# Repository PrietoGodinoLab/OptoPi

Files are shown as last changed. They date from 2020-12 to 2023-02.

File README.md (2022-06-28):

# OptoPi

### OptoPi Overview


Here, we present OptoPi, an open source, affordable (~ £600), behavioural arena with accompanying multi-animal tracking software. The system features highly customisable and reproducible visible and infrared illumination and allows for temporally precise optogenetic stimulation. OptoPi acquires images using a Raspberry Pi camera, features motorised LED-based illumination, Arduino control, as well as spectrum and irradiance monitoring to fine-tune
illumination conditions with real time feedback.

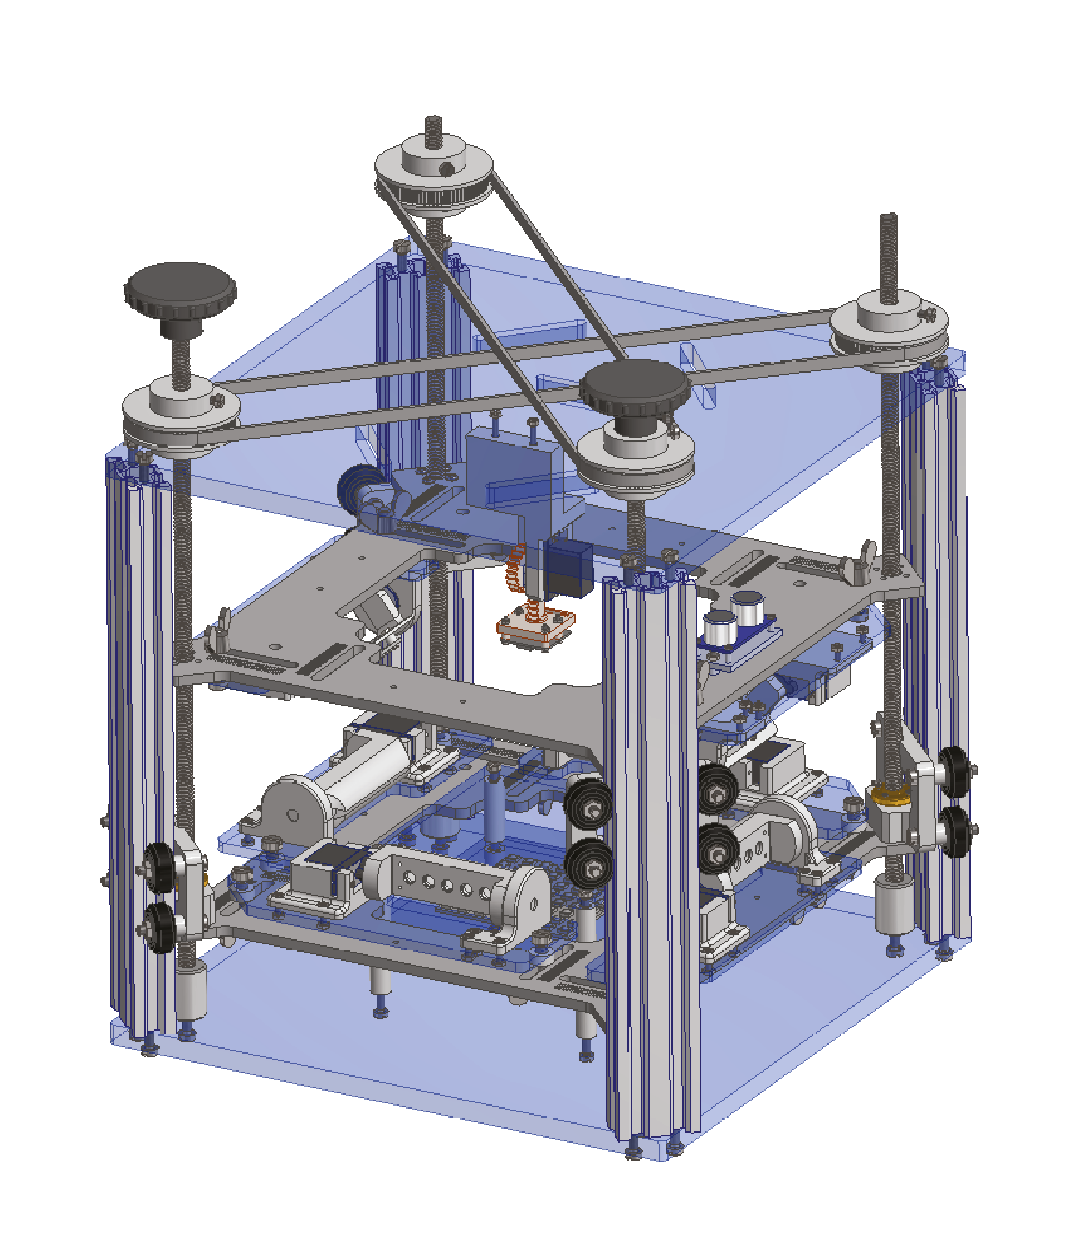
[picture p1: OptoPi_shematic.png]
 
Our open-source software (BIO) can be used to simultaneously track multiple animals while accurately keeping individual animal’s identity both in on-line and off-line modes. 

## BIO

For animal tracking we utilise and recommend BIO created by Joost de Folter. Currently, we use the [v1.7.6 release](https://github.com/folterj/BioImageOperation/releases/tag/v1.7.6). For the latest, actively maintained BIO repository see [BIO](https://github.com/folterj/BioImageOperation).

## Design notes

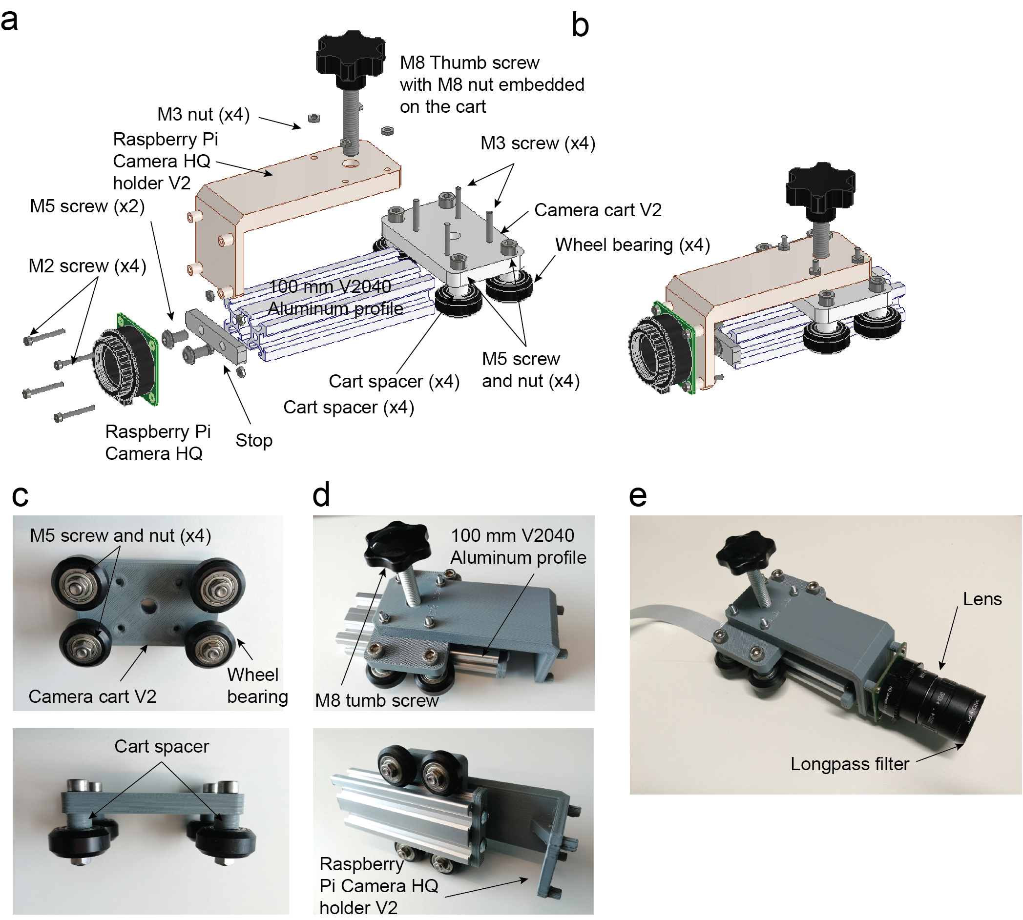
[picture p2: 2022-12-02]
OptoPi V1/Optional mechanical camera stage/Figure 10(2).png

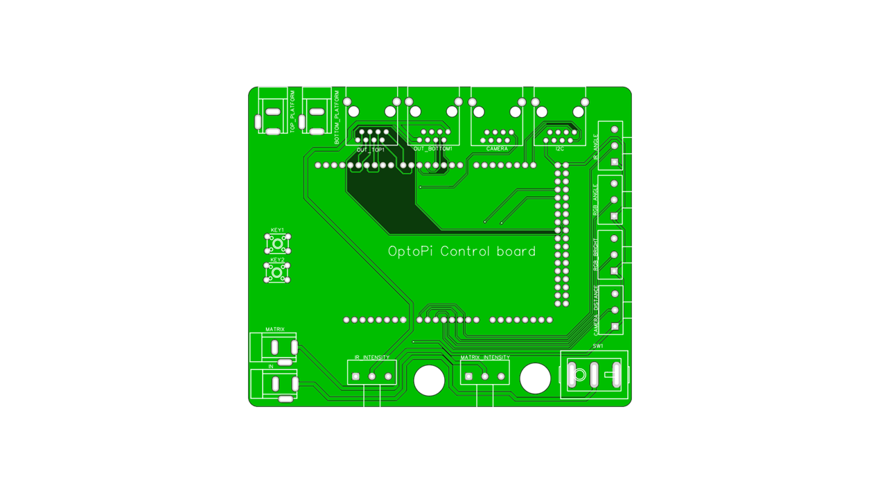
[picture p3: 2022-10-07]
OptoPi V1/Electronics Boards/Control board PCB/Control board.PNG

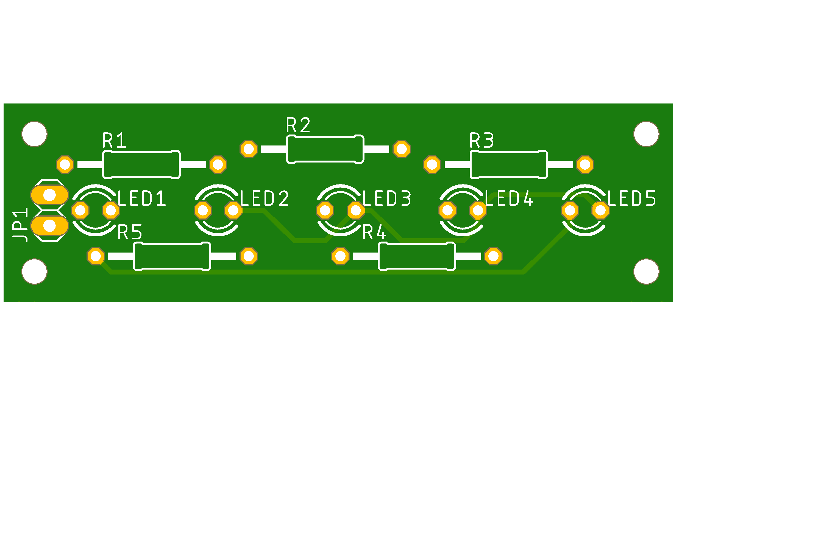
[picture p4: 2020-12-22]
OptoPi V1/Electronics Boards/IR LED Array PCB/LED ArrayTop.png

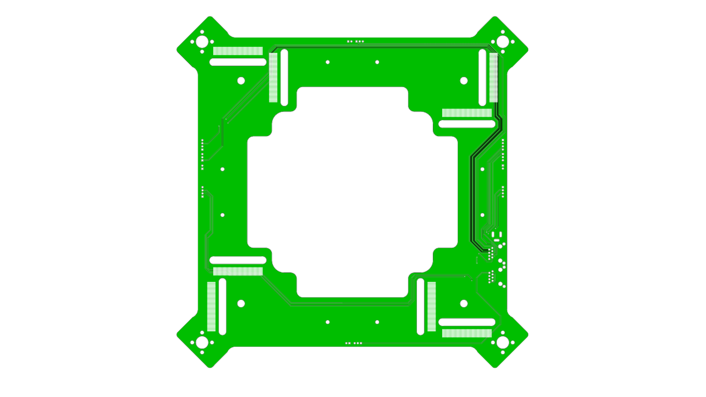
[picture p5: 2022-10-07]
OptoPi V1/Electronics Boards/Platform PCB/Platform.PNG

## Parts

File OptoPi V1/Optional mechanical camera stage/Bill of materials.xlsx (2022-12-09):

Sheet: Sheet1
BOM
1PC Silver V-slot 2040 European Standard Anodized Aluminum Profile Extrusion 100 | https://www.amazon.co.uk/KIRANDY-European-Standard-Extrusion-100-800mm/dp/B0B5Z3GMF8
2.1 mm Jack cables | https://www.amazon.co.uk/RUNCCI-YUN-Pigtail-Connector-connector-Systems/dp/B08ZMM8V3B
RJ45 connectors | https://uk.farnell.com/multicomp/mtj-881x1/modular-jack-tht-r-a-rj45-8p8c/dp/2112501
Barrel jack connectors (PCB) | https://uk.farnell.com/cliff-electronic-components/fc68148/socket-pcb-dc-power-2-1mm-pk10/dp/224959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
Control PCB
Platform PCB
M8 Thumb screw | https://www.amazon.co.uk/dp/B098JPSYMB?amp=&amp=
Ethernet cable (x2)
Power cable (Barrel jack male) (x2)

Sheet: Sheet2
Component | Quantity | Source
1PC Silver V-slot 2040 European Standard Anodized Aluminum Profile Extrusion 100 | 1 | Amazon (https://www.amazon.co.uk/KIRANDY-European-Standard-Extrusion-100-800mm/dp/B0B5Z3GMF8)
M8 Thumb screw | 1 | Amazon (https://www.amazon.co.uk/dp/B098JPSYMB?amp=&amp=)
Wheel bearing | 4 | Amazon (https://www.amazon.co.uk/gp/product/B07Q5WN3GK/ref=ppx_yo_dt_b_asin_title_o05_s00?ie=UTF8&psc=1)
M8 nut | 1
M3 screws (35 mm length) | 4
M3 nuts | 4
M5 screws (35 mm length) | 4
M5 nuts | 4
M5 screws (10 mm length) | 2
3D printed parts
Raspberry Pi HQ holder V2 | 1 | GitHub/OSFRepository
Camera cart V2 | 1 | GitHub/OSFRepository
Spacers | 4 | GitHub/OSFRepository
Stop | 5 | GitHub/OSFRepository

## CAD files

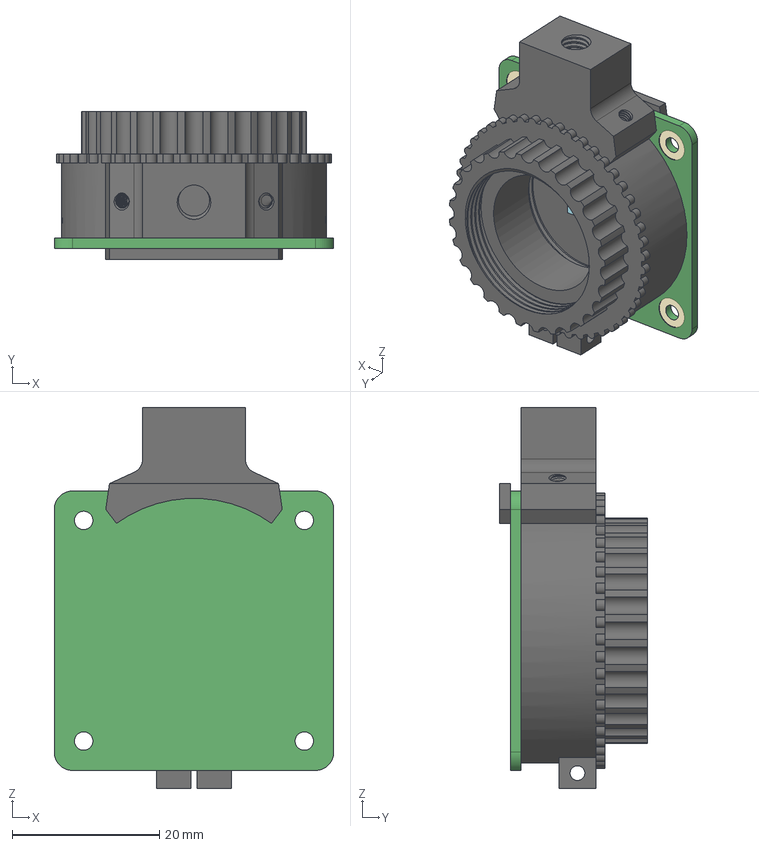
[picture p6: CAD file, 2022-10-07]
OptoPi V1/Mechanical components/Design files/Inventor Assembly/Raspberry Pi HQ Camera.step
38.0 x 20.1 x 51.8 mm

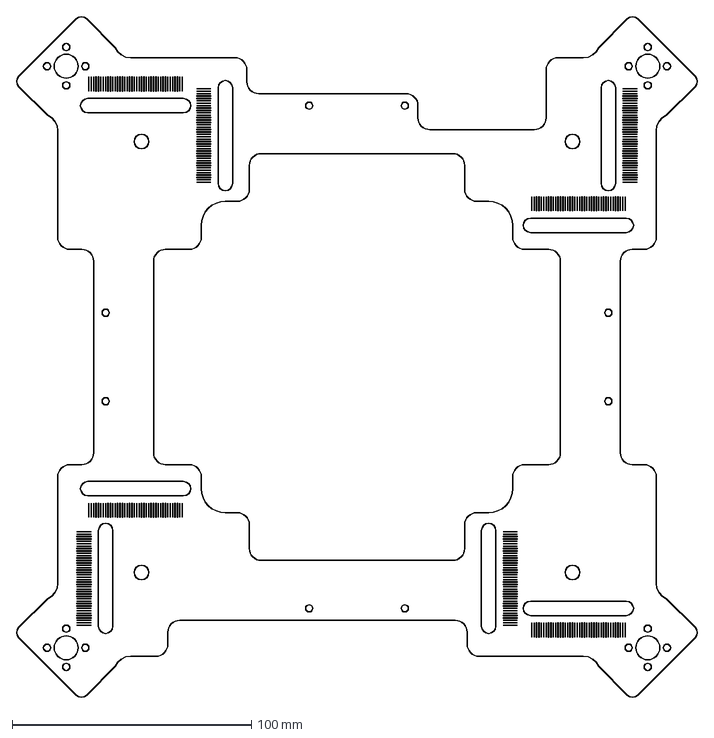
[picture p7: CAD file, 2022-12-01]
OptoPi V1/Mechanical components/DXF files/Platform/Platform spacer.dxf
284.9 x 284.9 mm

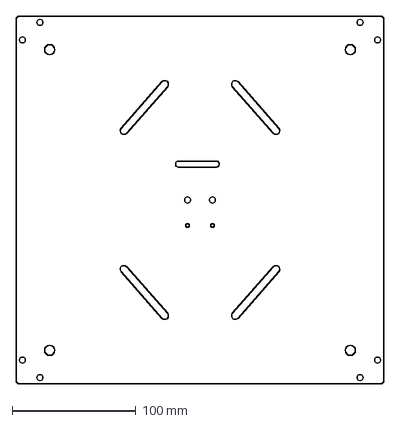
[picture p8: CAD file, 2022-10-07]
OptoPi V1/Mechanical components/DXF files/Structure/Roof.dxf
297.0 x 297.0 mm

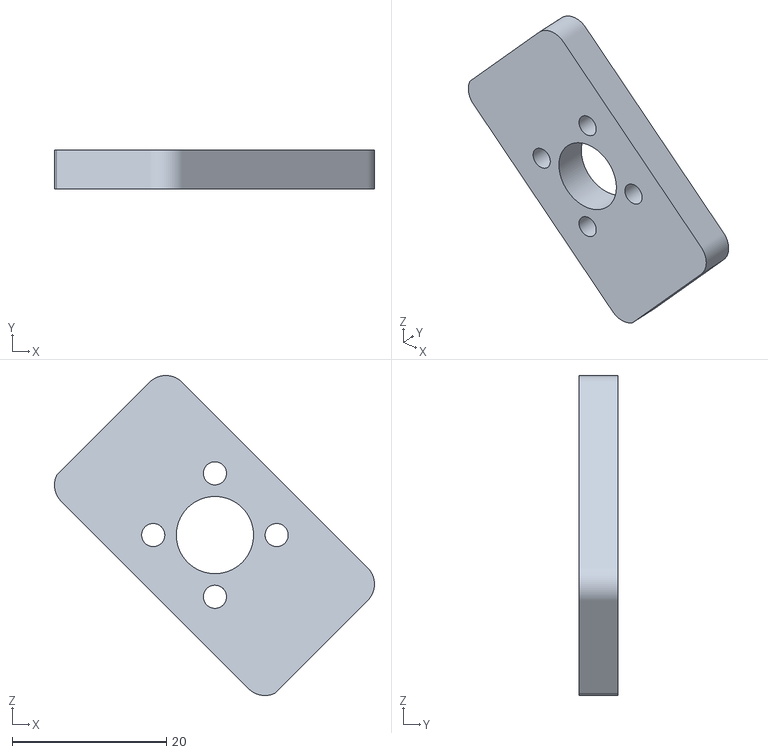
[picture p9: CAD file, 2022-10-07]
OptoPi V1/Mechanical components/STL files/Platform/Light sources platform spacer.stl
41.5 x 5.00 x 41.5

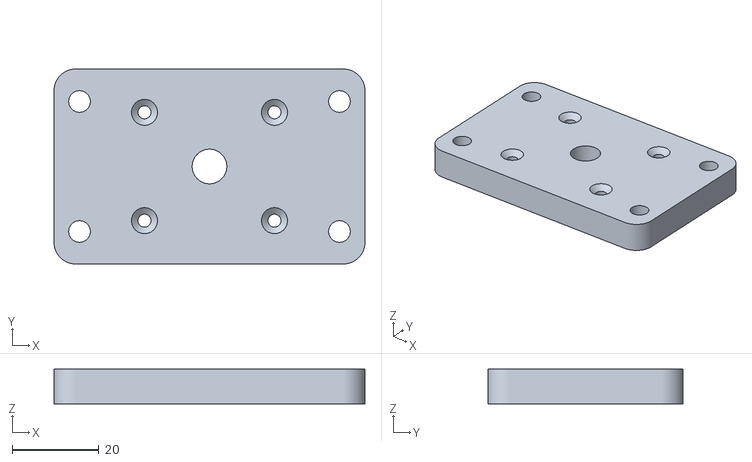
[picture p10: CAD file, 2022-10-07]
OptoPi V1/Optional mechanical camera stage/STL files/Camera_cart_V2.stl
71.8 x 45.0 x 8.00

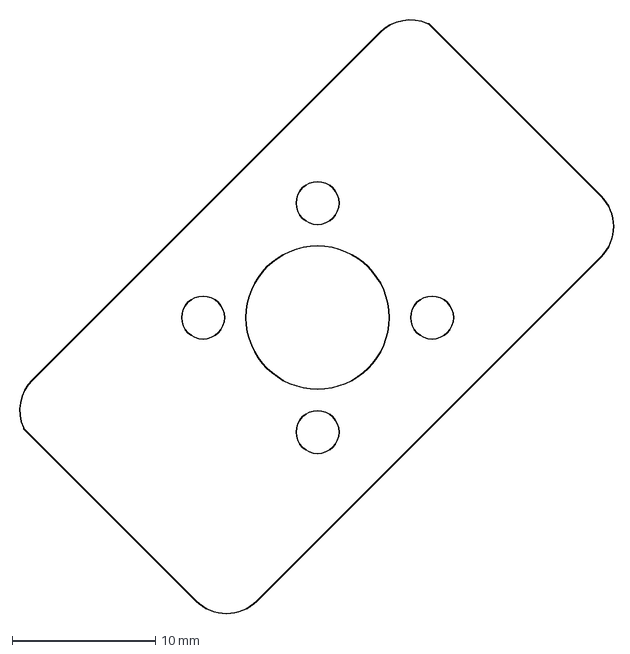
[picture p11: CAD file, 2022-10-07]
OptoPi V1/Mechanical components/Design files/Inventor Assembly/New parts/Light sources platform spacer.dxf
41.7 x 41.7 mm

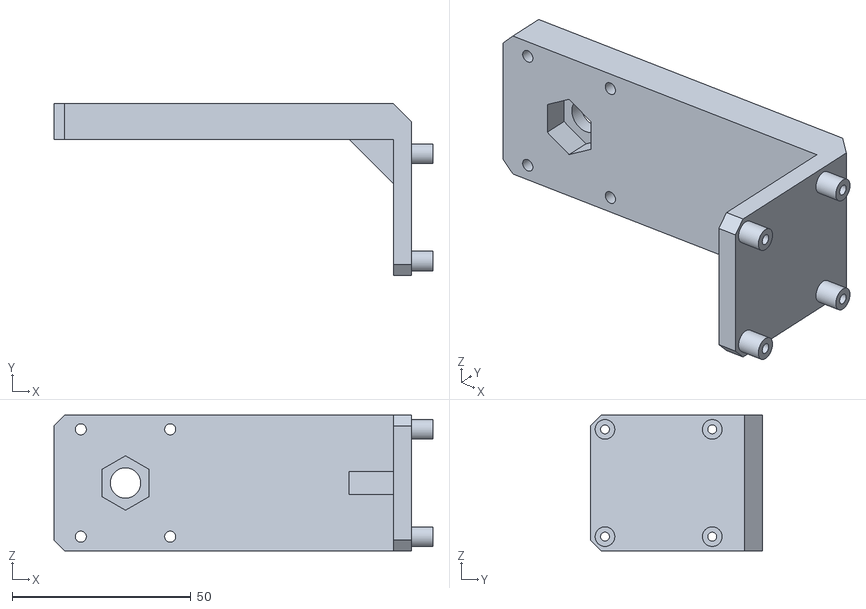
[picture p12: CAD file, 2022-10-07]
OptoPi V1/Optional mechanical camera stage/STL files/Raspberry pi HQ camera holder V2.stl
106.0 x 48.0 x 38.0

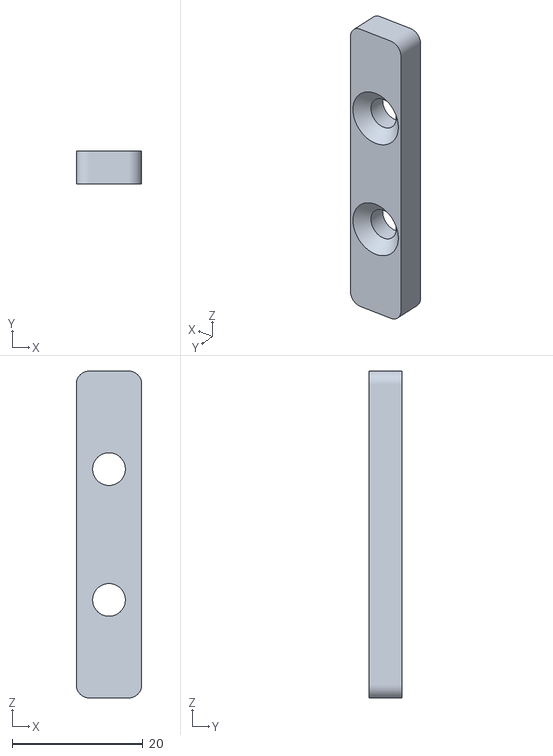
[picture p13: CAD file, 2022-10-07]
OptoPi V1/Optional mechanical camera stage/STL files/Stop.stl
10.0 x 5.00 x 50.0

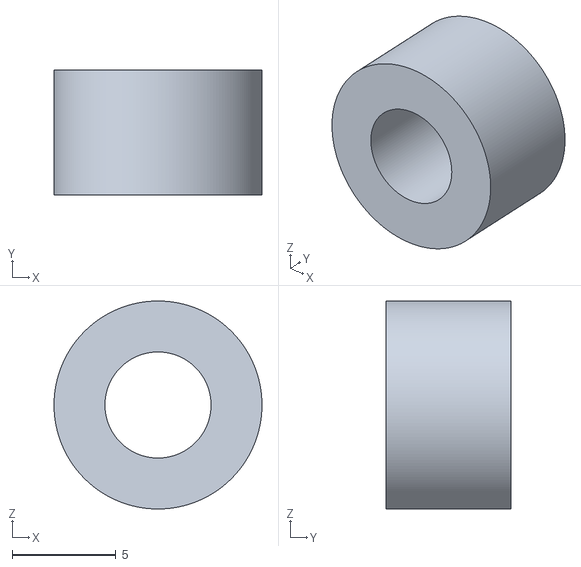
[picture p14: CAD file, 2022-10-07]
OptoPi V1/Optional mechanical camera stage/STL files/cart_spacer.stl
10.0 x 6.00 x 10.0

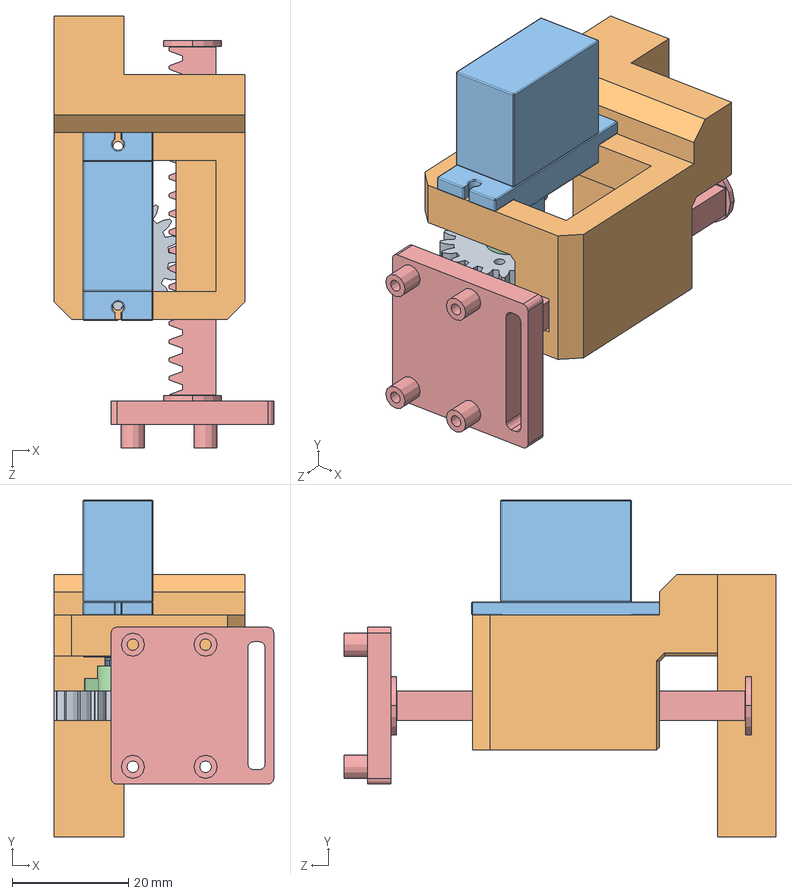
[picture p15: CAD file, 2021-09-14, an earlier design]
OptoPi V0/Mechanical components/Design files (Step and Autodesk inventor)/Inventor Assembly/Servo based linear actuator Pi Camera/Linear actuator assem 1.SLDASM
37.8 x 57.9 x 74.2 mm
ISO - Spur gear 1M 20T 20PA 5FW ---S20A75H50L5.0N
Linear actuator servo attachment
MG90s_servo
Servo lever
ISO - Rack-spur - rectangular 1M 20PA 5FW 5PH 125L---SAll

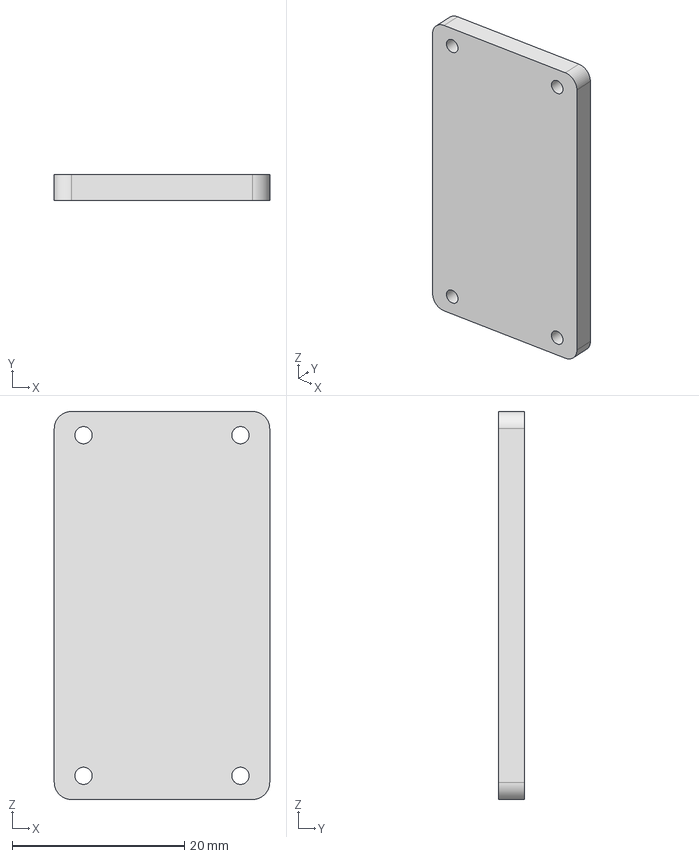
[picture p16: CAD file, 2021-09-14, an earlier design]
OptoPi V0/Electronics Boards/1-6 Connector/1-6 connector base.stp
25.0 x 3.00 x 45.0 mm

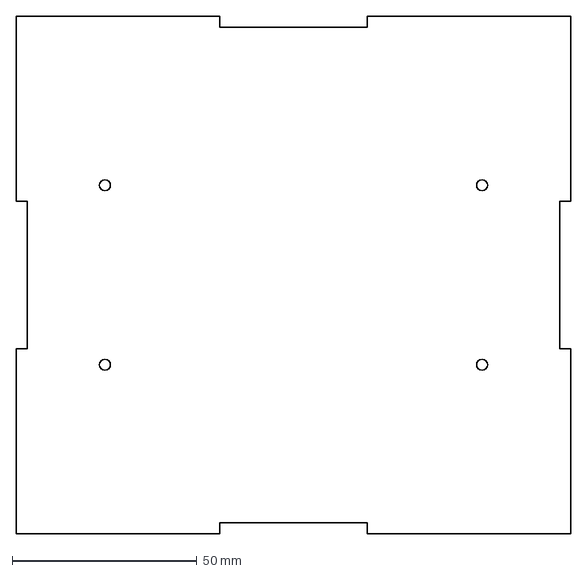
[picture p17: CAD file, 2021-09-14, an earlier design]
OptoPi V0/Electronics Boards/Electronics box/Electronics base.dxf
150.0 x 140.0 mm

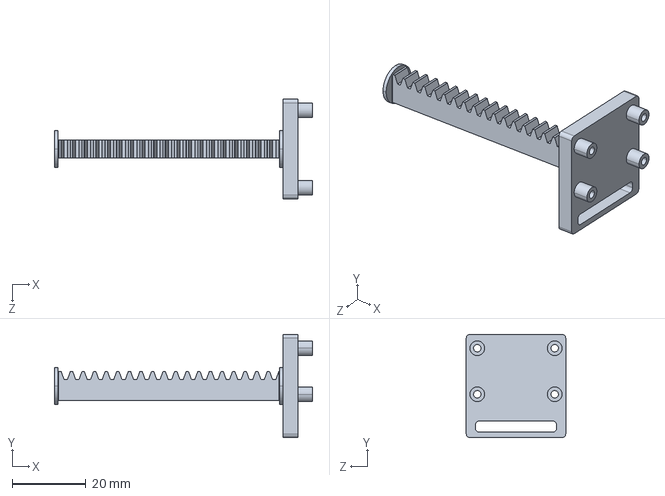
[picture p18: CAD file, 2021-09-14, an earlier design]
OptoPi V0/Mechanical components/Design files (Step and Autodesk inventor)/Inventor Assembly/Servo based linear actuator Pi Camera/ISO - Rack-spur - rectangular 1M 20PA 5FW 5PH 125L---SAll.STEP
70.0 x 28.0 x 27.0 mm

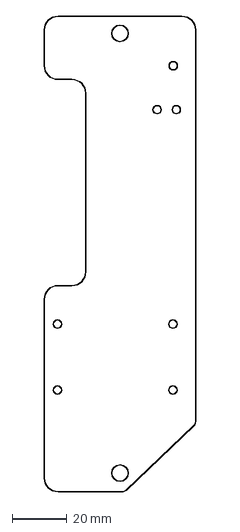
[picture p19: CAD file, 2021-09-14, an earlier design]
OptoPi V0/Mechanical components/Design files (Step and Autodesk inventor)/Inventor Assembly/Servo system holder.dxf
55.0 x 173.0 mm

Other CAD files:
OptoPi V1/Mechanical components/Design files/Inventor Assembly/Camera stage V2/Roof V2.dwg
OptoPi V1/Mechanical components/Design files/Inventor Assembly/New parts/Light sources platform spacer 2.dwg
OptoPi V1/Mechanical components/Design files/Inventor Assembly/New parts/Roof V2.dwg
OptoPi V0/Electronics Boards/1-6 Connector/1-6 connector base.dwg
OptoPi V0/Electronics Boards/1-6 Connector/1-6 connector base.dxf
OptoPi V0/Electronics Boards/1-6 Connector/OldVersions/Plastic base.0001.ipt
OptoPi V0/Electronics Boards/Electronics box/Electronics spacer.dxf
OptoPi V0/Electronics Boards/Electronics box/Lateral 1Wpot.dxf
OptoPi V0/Electronics Boards/Electronics box/Lateral 5Wpot.dxf
OptoPi V0/Electronics Boards/Electronics box/Lateral USB.dxf
OptoPi V0/Electronics Boards/Electronics box/Lateral power.dxf
OptoPi V0/Mechanical components/DXF files/Arena/Arena.dxf
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

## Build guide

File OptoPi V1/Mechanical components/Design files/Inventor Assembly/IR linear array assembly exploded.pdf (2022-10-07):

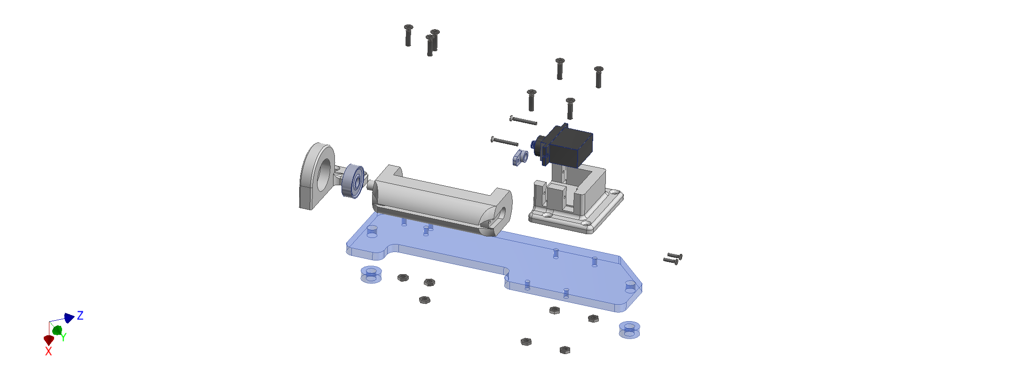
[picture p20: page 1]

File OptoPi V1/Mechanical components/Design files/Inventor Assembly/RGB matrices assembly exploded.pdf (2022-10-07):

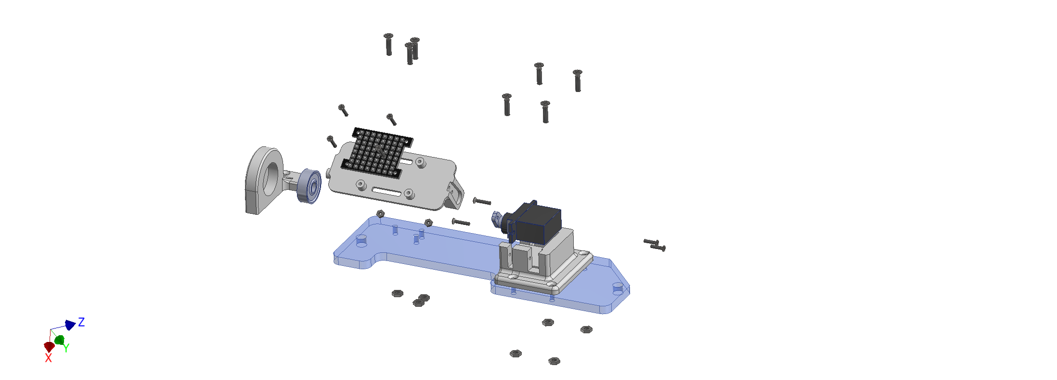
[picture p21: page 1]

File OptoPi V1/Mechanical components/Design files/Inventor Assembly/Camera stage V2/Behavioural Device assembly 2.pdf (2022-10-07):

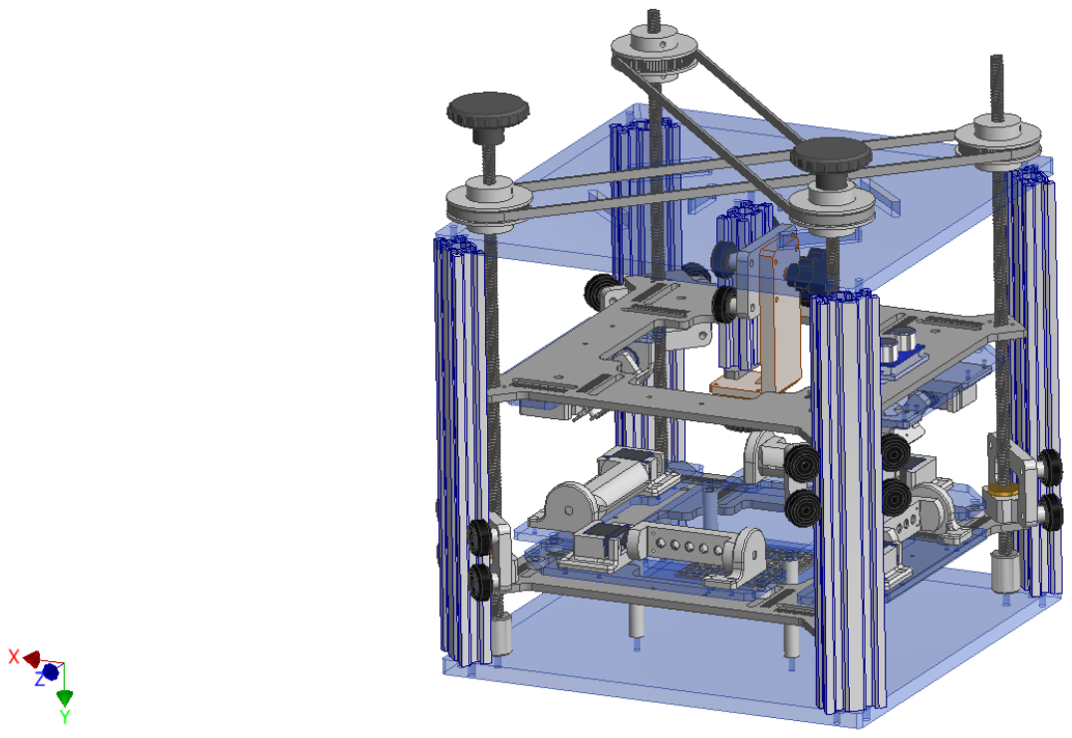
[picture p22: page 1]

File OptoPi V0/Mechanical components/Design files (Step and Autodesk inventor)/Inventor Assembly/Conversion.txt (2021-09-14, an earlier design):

Conversion Report:

Created by DWG TrueView DWG Convert Monday, November 16, 2020, 5:16 PM.

Conversion Summary

------------------

Conversion File Format:  AutoCAD 2004/LT 2004 Drawing Format

Conversion package type: In-place (overwrite files)

Converted DWG files:     2

Recovered DWG files:     0

Conversion errors:       0

Converted Files

---------------

Root Drawings:

	C:\Users\ferrerx\Desktop\CALM Lab\Syringe pump\Rail Syringe pump\Electronics base.dwg

	C:\Users\ferrerx\Desktop\CALM Lab\Syringe pump\Rail Syringe pump\Motor holder.dwg

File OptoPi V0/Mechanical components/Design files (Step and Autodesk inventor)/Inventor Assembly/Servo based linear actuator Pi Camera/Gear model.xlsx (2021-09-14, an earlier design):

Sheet: Sheet1
Cremallera |  | Gear
Modulo ( M ) | 1.00 | Numero de dientes ( N ) | 20
Paso ( P ) | 3.14 | Modulo ( M ) | 1.00
Altura total del diente ( H ) | 2.17 | Diametro primitivo (Dp) | 20.00
Espesor del diente ( e ) | 1.57 | Diametro exterior ( De ) | 22.00
( c ) | 1.57 | Altura del diente ( H ) | 2.17
Altura de la cabeza del diente ( L ) | 1.00
Semi angulo del diente ( α ) | 0.35
Radio del pie del diente ( r ) | 0.30 | Length (max)
Ancho del fondo del diente ( T ) | 0.84 | 125.6637061

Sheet: Sheet2
g | 9.81
S1 | 0.0115
S2 | 0.002
H | 0.045
t | 0.550750114

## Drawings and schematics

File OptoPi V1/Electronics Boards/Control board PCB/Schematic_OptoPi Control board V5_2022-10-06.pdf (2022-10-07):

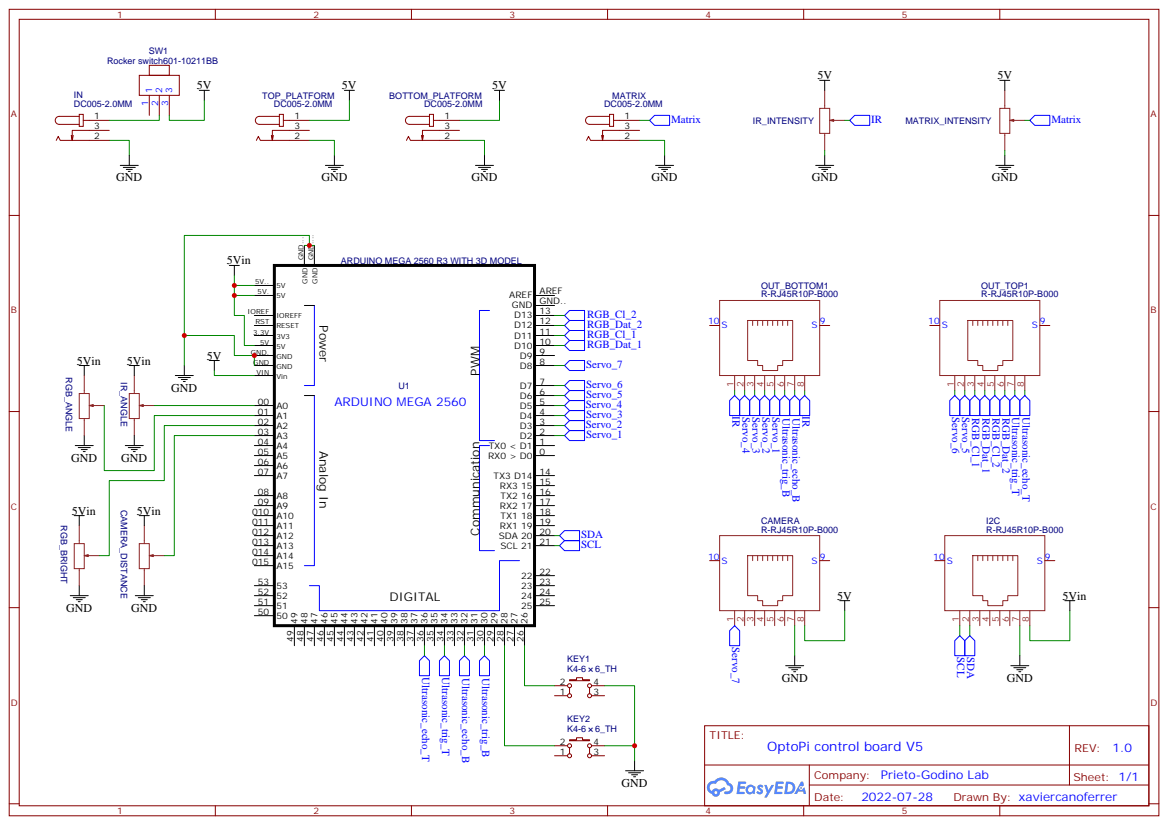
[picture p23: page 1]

GND GND....
ARDUINO MEGA 2560 R3 WITH 3D MODEL

Company: Prieto-Godino Lab

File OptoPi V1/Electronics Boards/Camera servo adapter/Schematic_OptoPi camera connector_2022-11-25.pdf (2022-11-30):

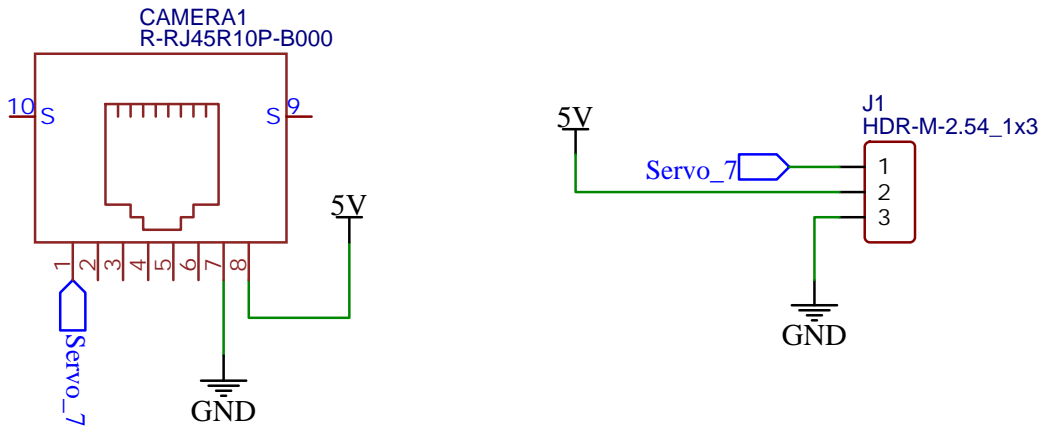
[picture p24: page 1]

Company: Prieto-Godino Lab

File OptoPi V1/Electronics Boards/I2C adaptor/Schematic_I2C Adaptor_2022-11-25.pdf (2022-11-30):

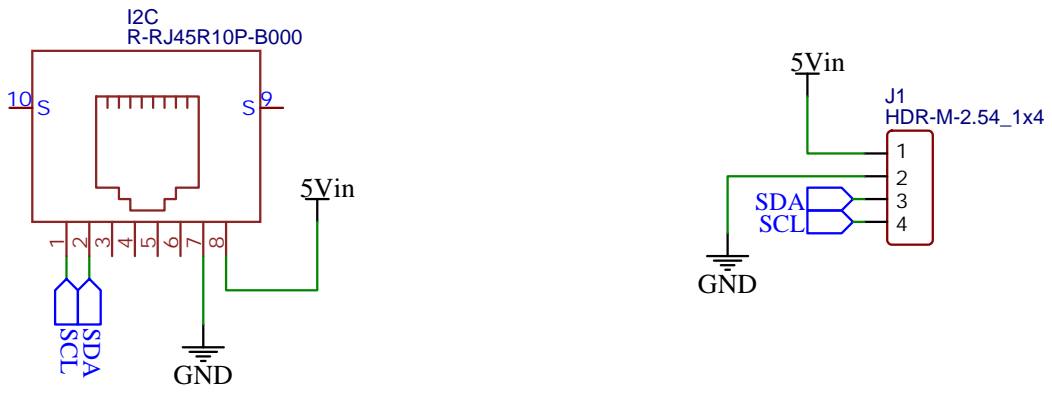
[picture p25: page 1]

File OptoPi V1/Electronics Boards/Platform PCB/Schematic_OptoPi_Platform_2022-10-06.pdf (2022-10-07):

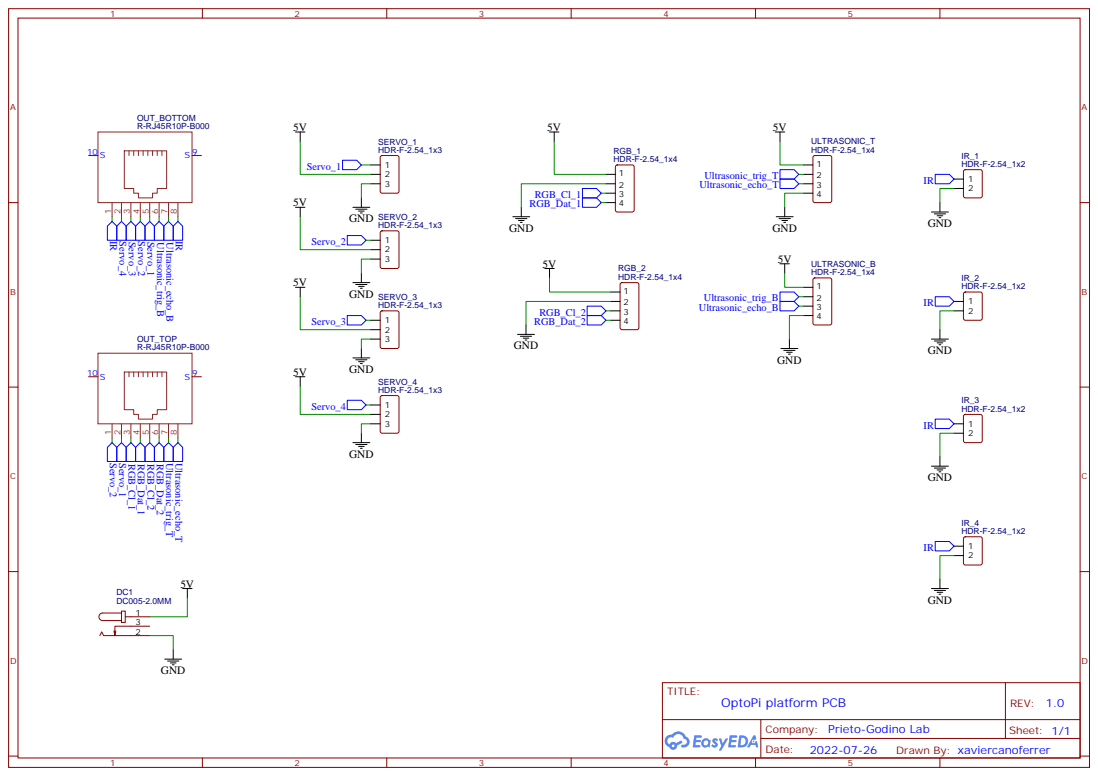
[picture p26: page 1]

Company: Prieto-Godino Lab

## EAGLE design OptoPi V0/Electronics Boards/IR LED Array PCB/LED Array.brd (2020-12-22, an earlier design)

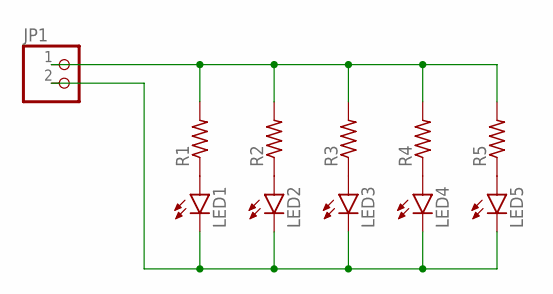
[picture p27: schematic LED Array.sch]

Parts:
JP1: PINHD-1X2; 1X02
LED1, LED2, LED3, LED4, LED5: LED3MM
R1, R2, R3, R4, R5: R-US_0207/12; 0207/12

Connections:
unnamed: LED1.A, R1.1
unnamed: LED3.A, R3.1
unnamed: LED2.A, R2.1
unnamed: LED4.A, R4.1
unnamed: JP1.2, LED1.K (C), LED2.K (C), LED3.K (C), LED4.K (C), LED5.K (C)
unnamed: JP1.1, R1.2, R2.2, R3.2, R4.2, R5.2
unnamed: LED5.A, R5.1

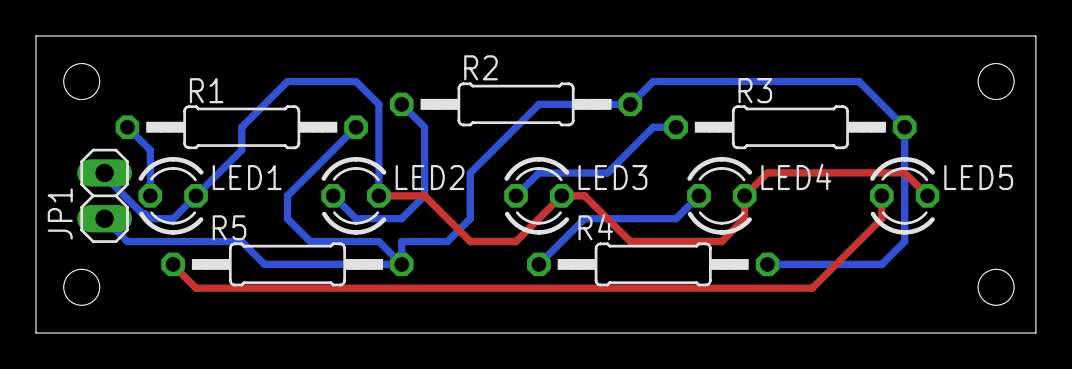
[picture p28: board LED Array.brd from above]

Board: 2 copper layers, 55.5 x 16.5 mm, 11 parts (0 on the bottom side), 7 nets.

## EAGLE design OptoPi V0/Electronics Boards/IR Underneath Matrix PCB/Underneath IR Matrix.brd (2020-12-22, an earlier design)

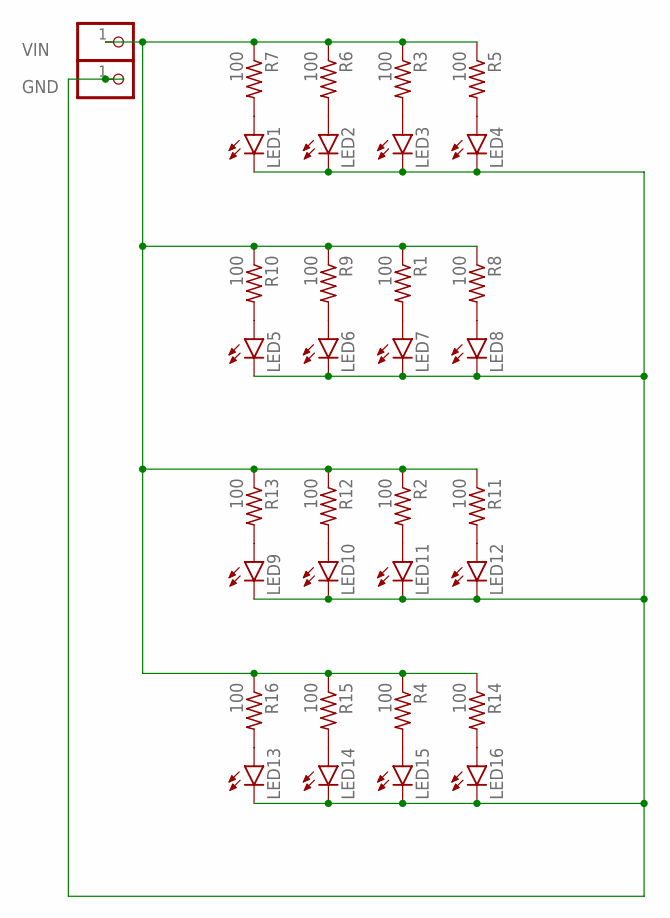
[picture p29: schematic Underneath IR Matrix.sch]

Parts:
GND: PINHD-1X1; 1X01
LED1, LED2, LED3, LED4, LED5, LED6, LED7, LED8, LED9, LED10, LED11, LED12, LED13, LED14, LED15, LED16: LED5MM
R1, R2, R3, R4, R5, R6, R7, R8, R9, R10, R11, R12, R13, R14, R15, R16: 100; 0207/10
VIN: PINHD-1X1; 1X01

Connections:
unnamed: LED5.A, R10.2
unnamed: LED6.A, R9.2
unnamed: LED4.A, R5.2
unnamed: LED8.A, R8.2
unnamed: LED7.A, R1.2
unnamed: LED1.A, R7.2
unnamed: LED2.A, R6.2
unnamed: LED12.A, R11.2
unnamed: GND.1, LED1.K (C), LED2.K (C), LED3.K (C), LED4.K (C), LED5.K (C), LED6.K (C), LED7.K (C), LED8.K (C), LED9.K (C), LED10.K (C), LED11.K (C), LED12.K (C), LED13.K (C), LED14.K (C), LED15.K (C), LED16.K (C)
unnamed: R1.1, R2.1, R3.1, R4.1, R5.1, R6.1, R7.1, R8.1, R9.1, R10.1, R11.1, R12.1, R13.1, R14.1, R15.1, R16.1, VIN.1
unnamed: LED15.A, R4.2
unnamed: LED3.A, R3.2
unnamed: LED9.A, R13.2
unnamed: LED10.A, R12.2
unnamed: LED11.A, R2.2
unnamed: LED13.A, R16.2
unnamed: LED14.A, R15.2
unnamed: LED16.A, R14.2

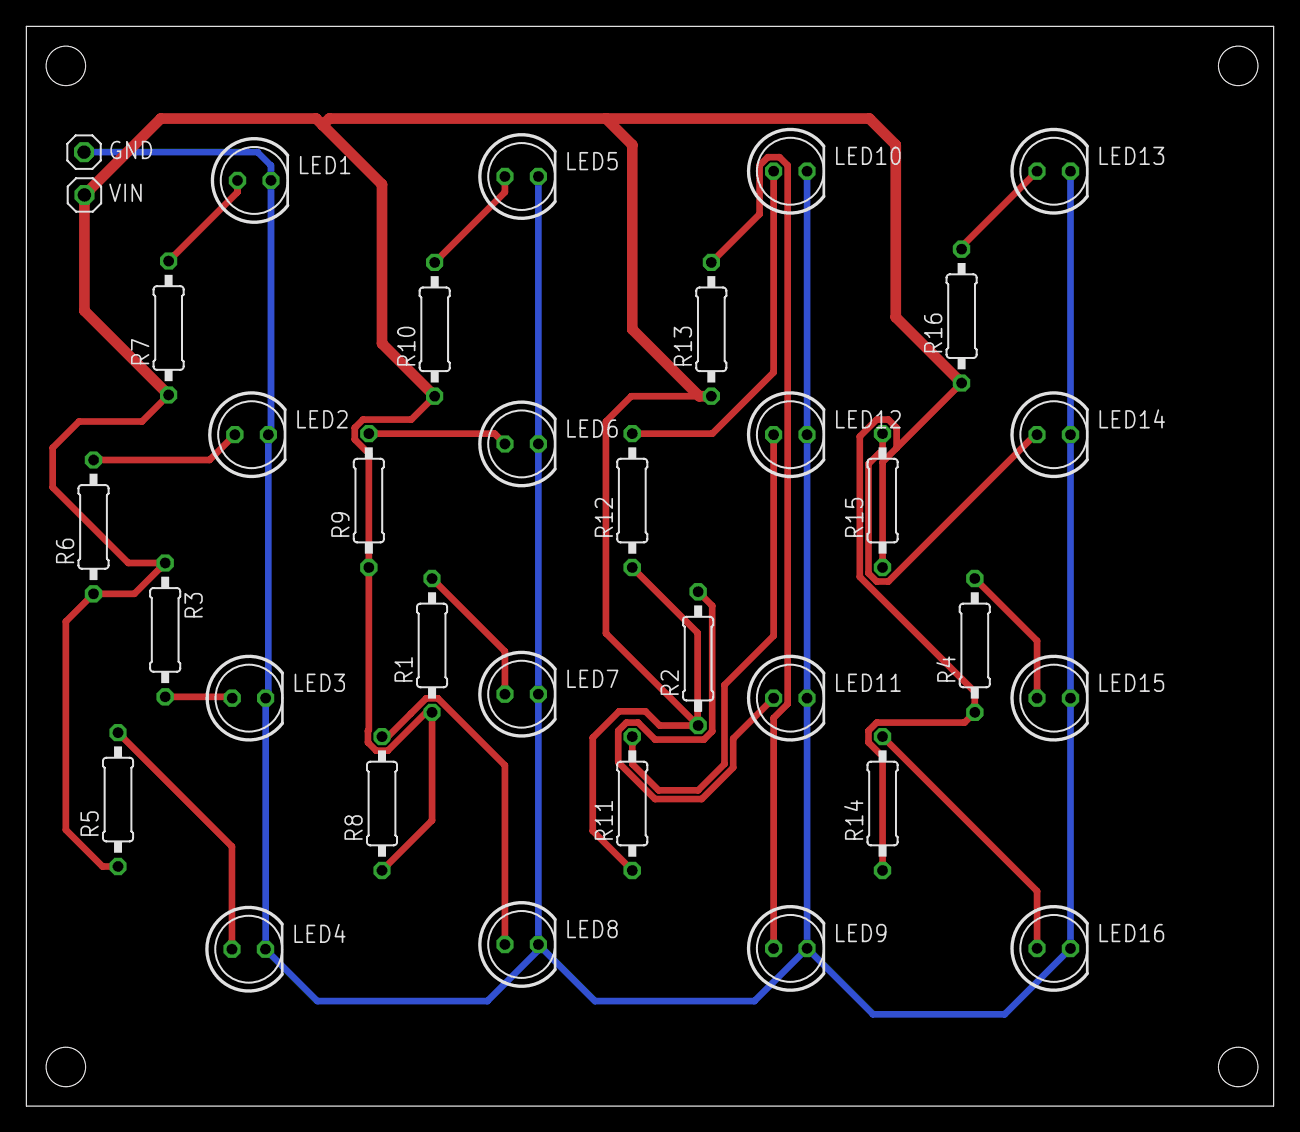
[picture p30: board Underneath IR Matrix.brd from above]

Board: 2 copper layers, 94.7 x 82.0 mm, 34 parts (0 on the bottom side), 18 nets.

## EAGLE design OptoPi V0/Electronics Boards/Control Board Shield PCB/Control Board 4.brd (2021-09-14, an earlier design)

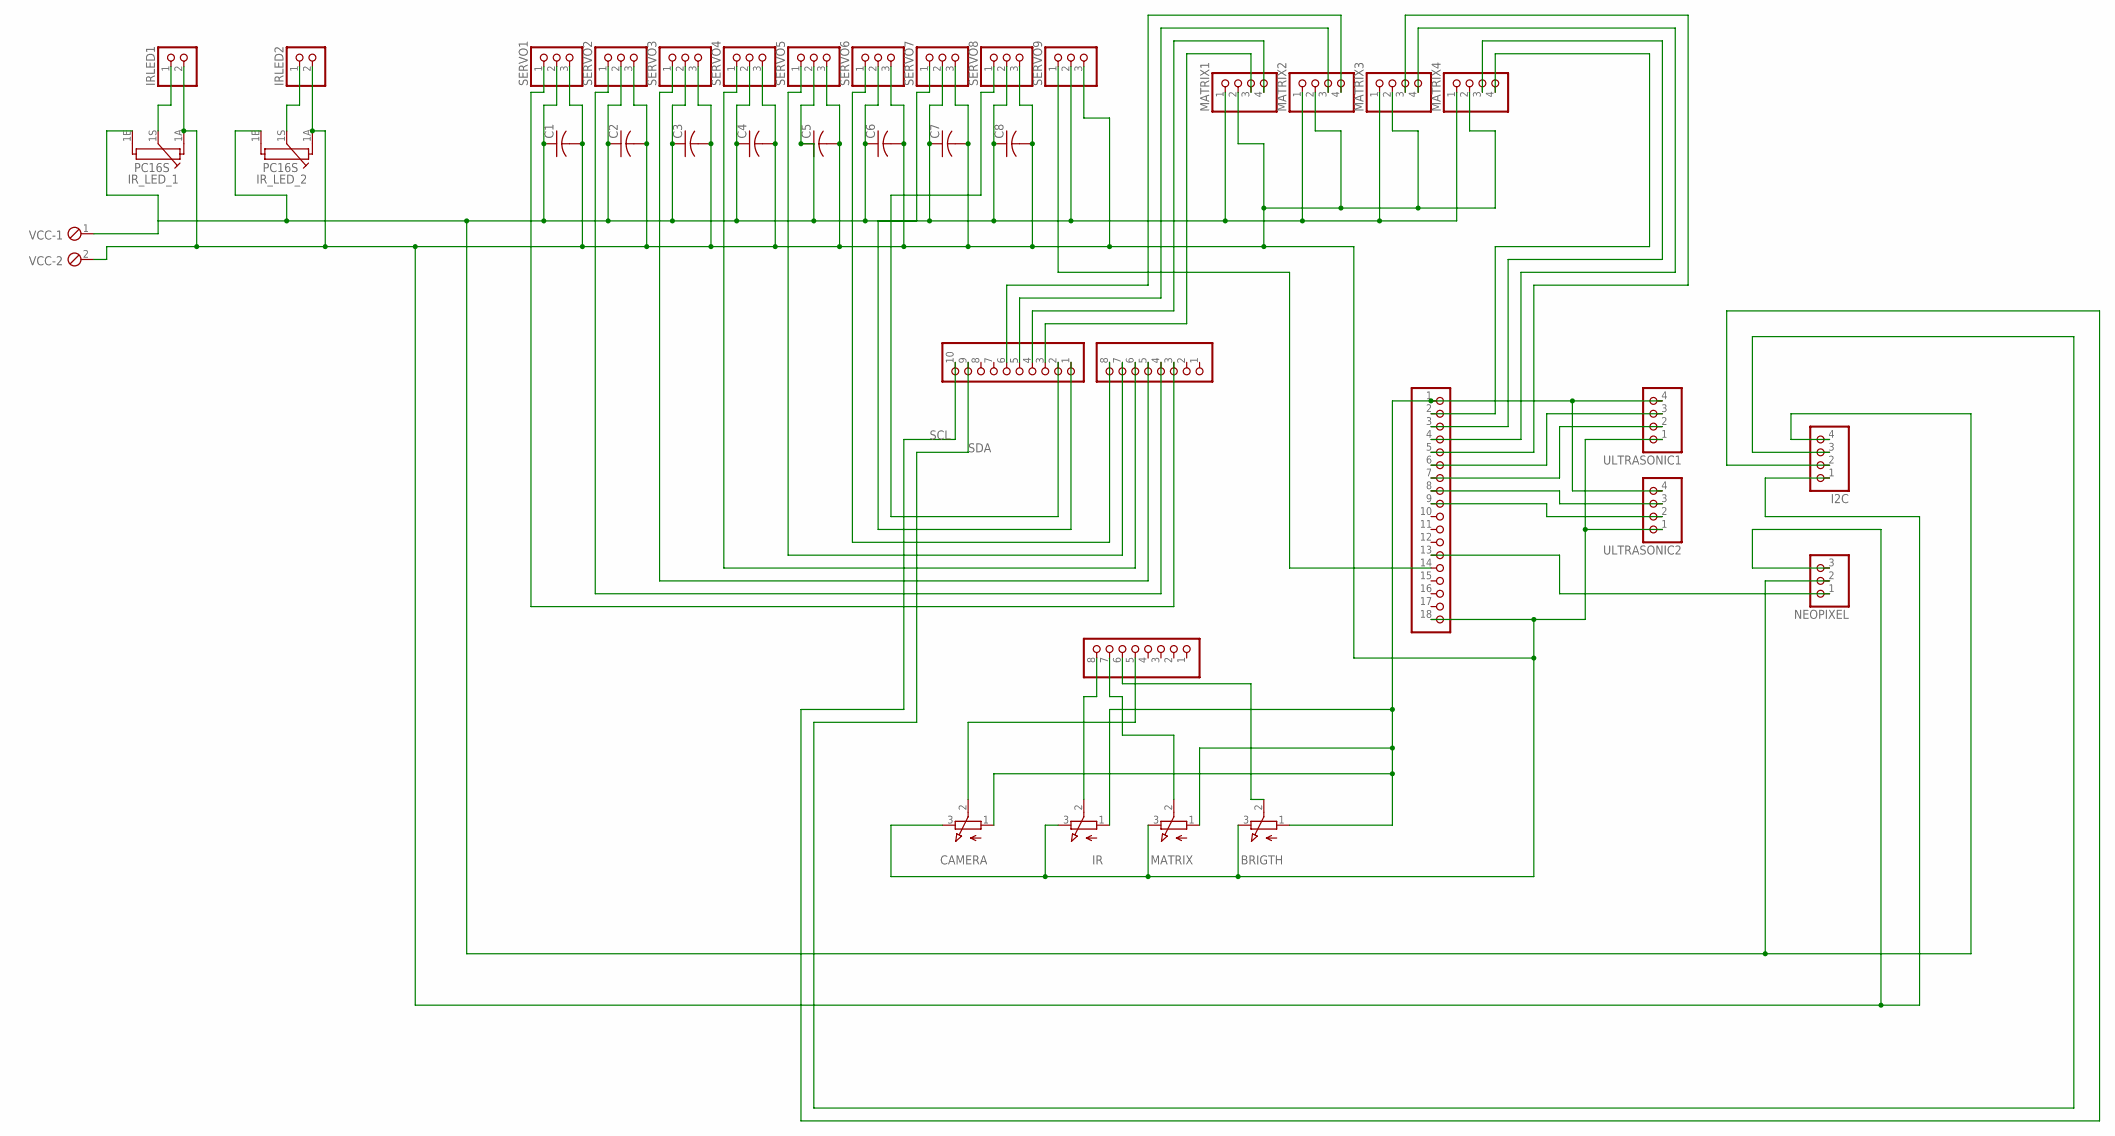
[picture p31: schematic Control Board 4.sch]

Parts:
BRIGTH: 3RP/1610N
C1, C2, C3, C4, C5, C6, C7, C8: C-US050-030X075; C050-030X075
CAMERA: 3RP/1610N
I2C: PINHD-1X4; 1X04
IR: 3RP/1610N
IRLED1, IRLED2: PINHD-1X2; 1X02
IR_LED_1, IR_LED_2: PC16S
MATRIX: 3RP/1610N
MATRIX1, MATRIX2, MATRIX3, MATRIX4: PINHD-1X4; 1X04
MEGABOTTOMCENTER: PINHD-1X8; 1X08
MEGALATERAL: PINHD-1X18; 1X18
MEGATOPCENTER: PINHD-1X8; 1X08
MEGATOPLEFT: PINHD-1X10_ARD; 1X10
NEOPIXEL: PINHD-1X3; 1X03
SERVO1, SERVO2, SERVO3, SERVO4, SERVO5, SERVO6, SERVO7, SERVO8, SERVO9: PINHD-1X3; 1X03
ULTRASONIC1, ULTRASONIC2: PINHD-1X4; 1X04
VCC: MPT2; 2POL254

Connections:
unnamed: MATRIX1.3, MEGATOPLEFT.3
unnamed: IR.2 (S), MEGABOTTOMCENTER.8
unnamed: MATRIX.2 (S), MEGABOTTOMCENTER.7
unnamed: BRIGTH.2 (S), MEGABOTTOMCENTER.6
unnamed: BRIGTH.1 (A), CAMERA.1 (A), IR.1 (A), MATRIX.1 (A), MEGALATERAL.1, ULTRASONIC1.4, ULTRASONIC2.4
unnamed: MEGALATERAL.7, ULTRASONIC1.2
unnamed: MEGALATERAL.6, ULTRASONIC1.3
unnamed: MEGALATERAL.8, ULTRASONIC2.3
unnamed: MEGALATERAL.9, ULTRASONIC2.2
unnamed: CAMERA.2 (S), MEGABOTTOMCENTER.5
unnamed: MATRIX1.4, MEGATOPLEFT.4
unnamed: MATRIX2.3, MEGATOPLEFT.5
unnamed: MATRIX2.4, MEGATOPLEFT.6
unnamed: MATRIX3.3, MEGALATERAL.5
unnamed: MATRIX3.4, MEGALATERAL.4
unnamed: MATRIX4.3, MEGALATERAL.3
unnamed: MATRIX4.4, MEGALATERAL.2
unnamed: IRLED2.1, IR_LED_2.1S
unnamed: MEGALATERAL.13, NEOPIXEL.1
unnamed: MEGALATERAL.14, SERVO9.1
unnamed: C1.1, C2.1, C3.1, C4.1, C5.1, C6.1, C7.1, C8.1, I2C.4, IR_LED_1.1E, IR_LED_2.1E, MATRIX1.1, MATRIX2.1, MATRIX3.1, MATRIX4.1, NEOPIXEL.2, SERVO1.2, SERVO2.2, SERVO3.2, SERVO4.2, SERVO5.2, SERVO6.2, SERVO7.2, SERVO8.2, SERVO9.2, VCC.1
unnamed: BRIGTH.3 (E), C1.2, C2.2, C3.2, C4.2, C5.2, C6.2, C7.2, C8.2, CAMERA.3 (E), I2C.1, IR.3 (E), IRLED1.2, IRLED2.2, IR_LED_1.1A, IR_LED_2.1A, MATRIX.3 (E), MATRIX1.2, MATRIX2.2, MATRIX3.2, MATRIX4.2, MEGALATERAL.18, NEOPIXEL.3, SERVO1.3, SERVO2.3, SERVO3.3, SERVO4.3, SERVO5.3, SERVO6.3, SERVO7.3, SERVO8.3, SERVO9.3, ULTRASONIC1.1, ULTRASONIC2.1, VCC.2
unnamed: MEGATOPCENTER.3, SERVO1.1
unnamed: MEGATOPCENTER.4, SERVO2.1
unnamed: MEGATOPCENTER.5, SERVO3.1
unnamed: MEGATOPCENTER.6, SERVO4.1
unnamed: MEGATOPLEFT.1, SERVO7.1
unnamed: MEGATOPCENTER.7, SERVO5.1
unnamed: MEGATOPCENTER.8, SERVO6.1
unnamed: MEGATOPLEFT.2, SERVO8.1
unnamed: IRLED1.1, IR_LED_1.1S
SCL: I2C.2, MEGATOPLEFT.10
SDA: I2C.3, MEGATOPLEFT.9

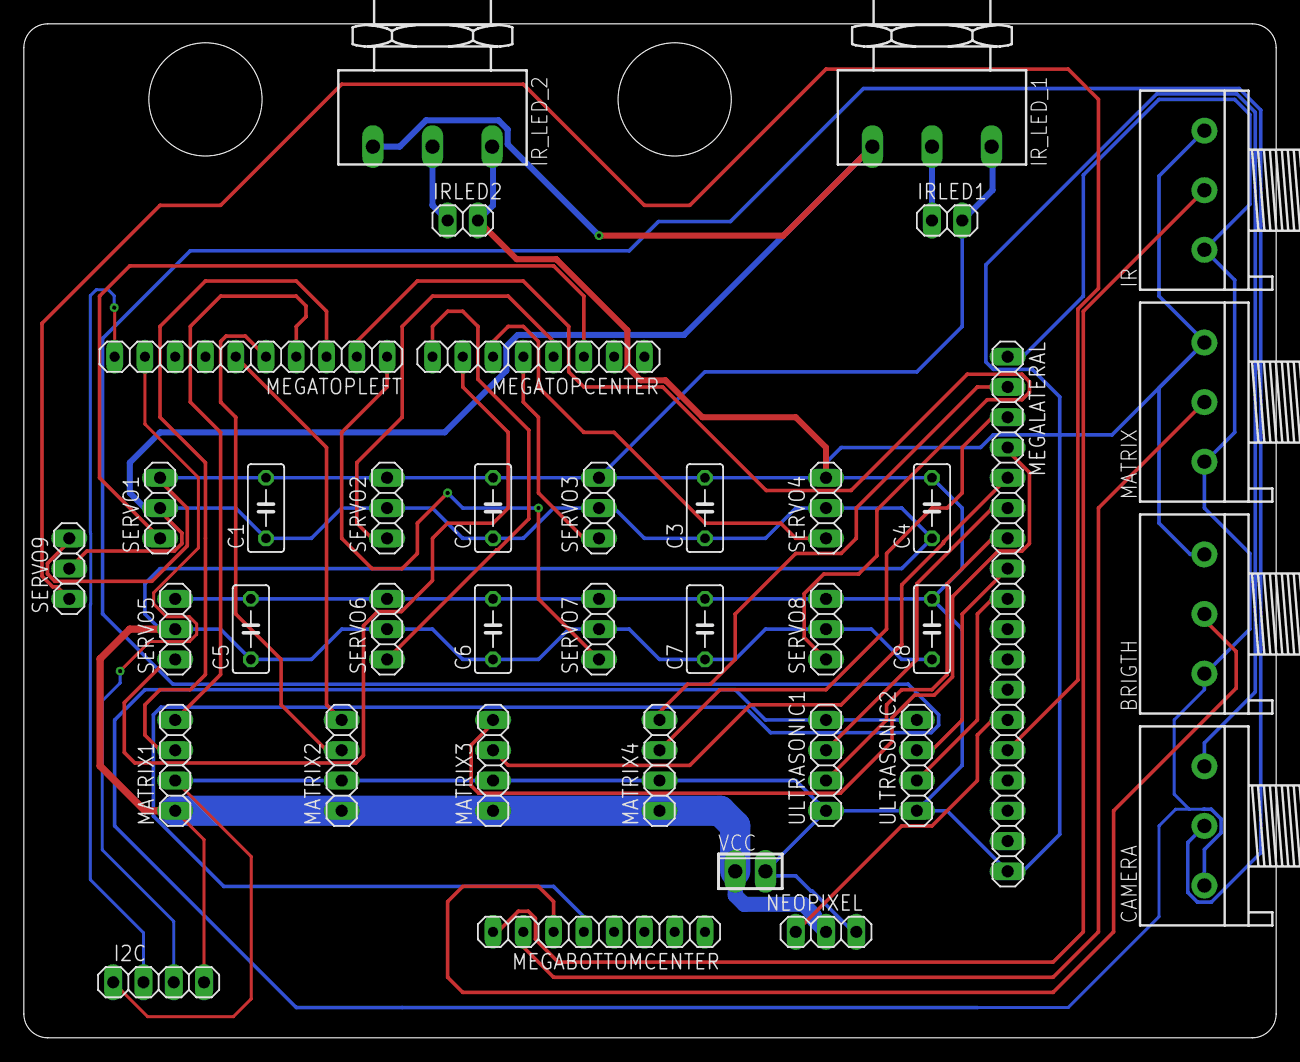
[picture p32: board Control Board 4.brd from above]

Board: 2 copper layers, 105.1 x 85.1 mm, 38 parts (0 on the bottom side), 33 nets.

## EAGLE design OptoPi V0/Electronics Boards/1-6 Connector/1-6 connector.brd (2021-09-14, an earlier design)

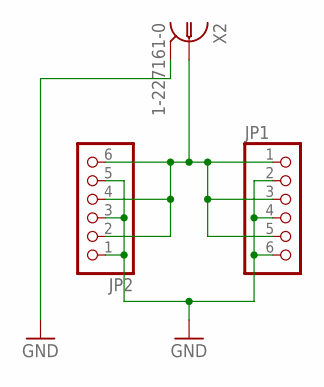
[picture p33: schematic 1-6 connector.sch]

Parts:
JP1, JP2: PINHD-1X6; 1X06
X2: 1-227161-0; AMP_227161

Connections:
GND: JP1.2, JP1.4, JP1.6, JP2.1, JP2.3, JP2.5, X2.2
unnamed: JP1.1, JP1.3, JP1.5, JP2.2, JP2.4, JP2.6, X2.1

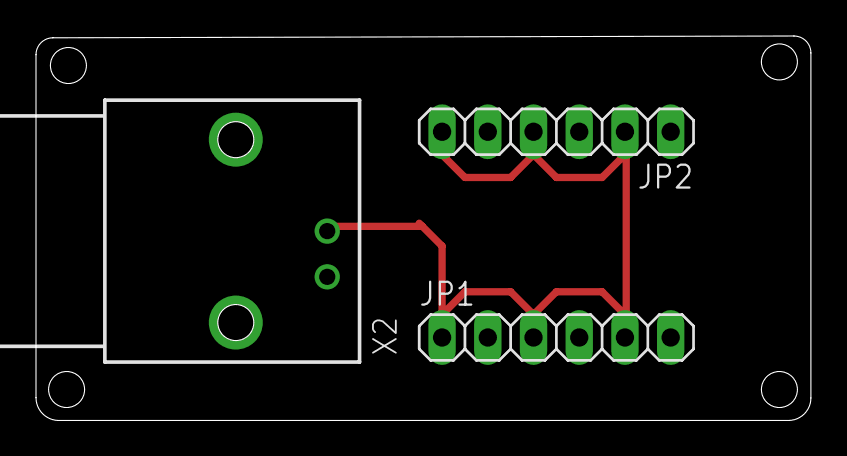
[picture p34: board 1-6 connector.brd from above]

Board: 2 copper layers, 43.0 x 21.4 mm, 3 parts (0 on the bottom side), 2 nets.

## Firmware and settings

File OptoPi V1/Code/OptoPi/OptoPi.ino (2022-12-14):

#include <SPI.h>
#include <Adafruit_GFX.h>
#include <Adafruit_DotStarMatrix.h>
#include <Adafruit_DotStar.h>
#include <Wire.h>
#include <Adafruit_Sensor.h>
#include <Servo.h>
#include <elapsedMillis.h>
#include <Adafruit_TSL2561_U.h>
#include <Adafruit_AS7341.h>

// Light stimulation Settings
const byte red = 255;
const byte green = 0;
const byte blue = 0;
byte brightness = 20;
int BRIGHTNESS;
byte brightness_low = 0;

// Variables to enable equations to calculate the irradiance
bool red_selected = true;
bool green_selected = false;
bool blue_selected = false;

elapsedMillis timeElapsed;
// delay in milliseconds between blinks of the Matrices
unsigned int DELAY = 1000;
// delay befor starting the stimulation
unsigned int DELAY_0 = 0;
bool state = LOW;
unsigned long previousMillis;
byte max_intensity = 255;

//MATRICES VARIABLES
#define DATAPIN_1    10
#define CLOCKPIN_1   11

#define DATAPIN_2    12
#define CLOCKPIN_2   13

#define DATAPIN_3    28
#define CLOCKPIN_3   26

#define DATAPIN_4    24
#define CLOCKPIN_4   22

Adafruit_DotStarMatrix matrix_1= Adafruit_DotStarMatrix(
                                  8, 8, DATAPIN_1, CLOCKPIN_1,
                                  DS_MATRIX_BOTTOM     + DS_MATRIX_LEFT +
                                  DS_MATRIX_ROWS + DS_MATRIX_PROGRESSIVE,
                                  DOTSTAR_BGR);

Adafruit_DotStarMatrix matrix_2= Adafruit_DotStarMatrix(
                                  8, 8, DATAPIN_2, CLOCKPIN_2,
                                  DS_MATRIX_BOTTOM     + DS_MATRIX_LEFT +
                                  DS_MATRIX_ROWS + DS_MATRIX_PROGRESSIVE,
                                  DOTSTAR_BGR);
                                  
Adafruit_DotStarMatrix matrix_3= Adafruit_DotStarMatrix(
                                  8, 8, DATAPIN_3, CLOCKPIN_3,
                                  DS_MATRIX_BOTTOM     + DS_MATRIX_LEFT +
                                  DS_MATRIX_ROWS + DS_MATRIX_PROGRESSIVE,
                                  DOTSTAR_BGR);
                                  
Adafruit_DotStarMatrix matrix_4= Adafruit_DotStarMatrix(
                                  8, 8, DATAPIN_4, CLOCKPIN_4,
                                  DS_MATRIX_BOTTOM     + DS_MATRIX_LEFT +
                                  DS_MATRIX_ROWS + DS_MATRIX_PROGRESSIVE,
                                  DOTSTAR_BGR);

// ULTRASONIC SENSOR VARIABLES
int trigPin = 30;    // Trigger
int echoPin = 32;    // Echo
float duration, cm, inches;

const int numReadings = 10;

int readings[numReadings];      // the readings from the analog input
int readIndex = 0;              // the index of the current reading
float total = 0;                  // the running total
float average = 0;                // the average

// ULTRASONIC SENSOR VARIABLES
int trigPin_2 = 34;   
int echoPin_2 = 36;    
float duration_2, cm_2;

int readings_2[numReadings];      
int readIndex_2 = 0;            
float total_2 = 0;                  
float average_2 = 0;      

int distance_camera;
int pot2;

// SERVO MOTORS VARIABLES

//Angle variable for the IR LED Arrays
int angle_1 = 0;

//Angle variable for the RGB Matrix
int angle_2 = 0;

//Angle corrected variable for the IR LED Arrays
int  angle_corrected_1 = 0;
int  angle_corrected_2 = 0;
int  angle_corrected_3 = 0;
int  angle_corrected_4 = 0;

int offset_1 = -15;
int offset_2 = -12;
int offset_3 = 0;
int offset_4 = 0;

////Angle corrected variable for the RGB Matrix
//int  angle_corrected_5 = 0;
int  angle_corrected_6 = 0;
int  angle_corrected_7 = 0;
//int  angle_corrected_8 = 0;

int offset_6 = 0;
int offset_7 = 0;

// Servo objects
Servo servo1; 
Servo servo2; 
Servo servo3; 
Servo servo4; 
Servo servo5; 
Servo servo6; 
Servo servo7; 
//Servo servo8; 

// TSL2561 Sensor motor configuration
Adafruit_TSL2561_Unified tsl = Adafruit_TSL2561_Unified(TSL2561_ADDR_FLOAT, 12345);

void configureSensor(void)
{
  /* You can also manually set the gain or enable auto-gain support */
  // tsl.setGain(TSL2561_GAIN_1X);      /* No gain ... use in bright light to avoid sensor saturation */
  // tsl.setGain(TSL2561_GAIN_16X);     /* 16x gain ... use in low light to boost sensitivity */
  tsl.enableAutoRange(true);            /* Auto-gain ... switches automatically between 1x and 16x */
  
  /* Changing the integration time gives you better sensor resolution (402ms = 16-bit data) */
  //tsl.setIntegrationTime(TSL2561_INTEGRATIONTIME_13MS);      /* fast but low resolution */
  //tsl.setIntegrationTime(TSL2561_INTEGRATIONTIME_101MS);  /* medium resolution and speed   */
  tsl.setIntegrationTime(TSL2561_INTEGRATIONTIME_402MS);  /* 16-bit data but slowest conversions */
}

// AS7341 object declaration
Adafruit_AS7341 as7341;

int value;

void setup() 
{
  
  Serial.begin(9600);

  //Setup Servo motors
  servo1.attach(2); // Servo objects pin attachment
  servo2.attach(3);
  servo3.attach(4);
  servo4.attach(5);
  servo5.attach(6);
  servo6.attach(7);
  servo7.attach(8);
//  servo8.attach(9);
  
  //Setup Ultrasonic sensor 1
  pinMode(trigPin, OUTPUT);
  pinMode(echoPin, INPUT);
  for (int thisReading = 0; thisReading < numReadings; thisReading++) 
  {
    readings[thisReading] = 0;
  }
  
  //Setup Ultrasonic sensor 2
  pinMode(trigPin_2, OUTPUT);
  pinMode(echoPin_2, INPUT);
  for (int thisReading_2 = 0; thisReading_2 < numReadings; thisReading_2++) 
  {
    readings_2[thisReading_2] = 0;
  }

  //Setup Matrices
  matrix_1.begin();

  matrix_2.begin();

  matrix_3.begin();

  matrix_4.begin();

  // Configure the light intensity sensor
  configureSensor();

  // Initialize the AS7341 spectral sensor and settings
  as7341.begin();

  as7341.setATIME(100);
  as7341.setASTEP(999);
  as7341.setGain(AS7341_GAIN_256X);
  
  //Check the values of the potentiometers preset and adjust once
  
  // CAMERA DISTANCE
  Camera();

  // IR ARRAYS ANGLE
  IR_Lights_angle();
    
  // RGB MATRICES ANGLE
  RGB_matrices_angle();

  Set_Matrix_Color_Brightness(red, green, blue, brightness_low);

}



void loop() 
{
    
    //Read the state (0 or 1) from serial sent from the Raspberry Pi
    //Blink_from_Pi_serial();

    //Read the RGB matrix intensity value(0 to 255) from serial sent from the Raspberry Pi
    //Custom_intensity_from_Pi_serial();

   String command = Serial.readString();
   while (command == "begin")
   {
   
   //Setting functions
   //Settings();

   //RGB MATRICES STIMULATION
   //Set_Matrix_Color_Brightness(0, 0, 0, 0);

   //Intensity ramp behaviural function
   //intensity_ramp(max_intensity,DELAY);
    
   //Blinking matrices behaviural function
   blinking(DELAY_0, DELAY);

   //Read irradiance
   //read_irradiance();
   }


}

////////////////////////////////////FUNCTIONS////////////////////////////////////////////////////////
void Settings()
{
  //  //READ DISTANCE ULTRASONIC SENSOR 1(Top)
  Read_distance_sensor_1();
//  
//  //READ DISTANCE ULTRASONIC SENSOR 2(Bottom)
  Read_distance_sensor_2();
//  
//  // CAMERA DISTANCE
  Camera();
//  
//  // IR ARRAYS ANGLE
  IR_Lights_angle();
//
//  // RGB MATRICES ANGLE
  RGB_matrices_angle();
  //
  Set_Matrix_Brightness();

  //Bottom distance 
   Serial.print(" Db: ");
   Serial.print(average_2);
   //Top distance 
   Serial.print(" Dt: ");
   Serial.print(average);
   //IR angle
   Serial.print(" IR: ");
   Serial.print(angle_1);
   //RGB angle
   Serial.print(" RGB: ");
   Serial.print(angle_2);
   //Camera distance
   Serial.print(" Cd: ");
   Serial.print(distance_camera);
   //RGB brightness
   Serial.print(" Bright: ");
   Serial.print(BRIGHTNESS);
   Serial.println();
}
void IR_Lights_angle()
  {
   //Reading from the first potentiometer and converting to an angle from 0-180 deg
   angle_1 = analogRead(A0)*0.176;
   
   //Send position to Servo 1
   angle_corrected_1 = angle_1 + offset_1;
   servo1.write(angle_corrected_1);
 
   //Send position to Servo 2
   angle_corrected_2 = angle_1 + offset_2 ;
   servo2.write(angle_corrected_2);
 
   //Send position to Servo 3
   angle_corrected_3 = angle_1 + offset_3;
   servo3.write(angle_corrected_3);

   //Send position to Servo 4
   angle_corrected_4 = angle_1 + offset_4;
   servo4.write(angle_corrected_4);
  }

void RGB_matrices_angle()
  {
   //Reading from the first potentiometer and converting to an angle from 0-180 deg
   angle_2 = analogRead(A1)*0.176;
     
   //Send position to Servo 6
   angle_corrected_6 = angle_2 + offset_6;
   servo6.write(angle_corrected_6);

   //Send position to Servo 7
   angle_corrected_7 = angle_2 + offset_7;
   servo7.write(angle_corrected_7);
  }


void Camera()
  {
   pot2 = analogRead(A3);
   distance_camera = map(pot2, 0,1023,0,180);
   servo5.write(distance_camera); 
  }

void Read_distance_sensor_1()
  {
    digitalWrite(trigPin, LOW);
    delayMicroseconds(5);
    digitalWrite(trigPin, HIGH);
    delayMicroseconds(10);
    digitalWrite(trigPin, LOW);
    pinMode(echoPin, INPUT);
    duration = pulseIn(echoPin, HIGH);
   
    // Convert the time into a distance
    cm = (duration/2) / 29.1;     
  
    // subtract the last reading
    total = total - readings[readIndex];
    // read from the sensor
    readings[readIndex] = cm;
    // add the reading to the total
    total = total + readings[readIndex];
    // advance to the next position in the array
    readIndex = readIndex + 1;
  
    // if we're at the end of the array...
    if (readIndex >= numReadings) 
    {
      // ...wrap around to the beginning
      readIndex = 0;
    }
    // calculate the average
    average = total / numReadings;
  }

void Read_distance_sensor_2()
  {
    digitalWrite(trigPin_2, LOW);
    delayMicroseconds(5);
    digitalWrite(trigPin_2, HIGH);
    delayMicroseconds(10);
    digitalWrite(trigPin_2, LOW);
    pinMode(echoPin_2, INPUT);
    duration_2 = pulseIn(echoPin_2, HIGH);
   
    // Convert the time into a distance
    cm_2 = (duration_2/2) / 29.1;     
  
    // subtract the last reading
    total_2 = total_2 - readings_2[readIndex_2];
    // read from the sensor
    readings_2[readIndex_2] = cm_2;
    // add the reading to the total
    total_2 = total_2 + readings_2[readIndex_2];
    // advance to the next position in the array
    readIndex_2 = readIndex_2 + 1;
  
    // if we're at the end of the array...
    if (readIndex_2 >= numReadings) 
    {
      // ...wrap around to the beginning
      readIndex_2 = 0;
    }
    // calculate the average
    average_2 = total_2 / numReadings;

  }

void Set_Matrix_Brightness()
  {
     //SET THE LEVEL OF BRIGHTNESS Warning: The maximum level is set at 200 because more will exceed the limit of 2.5A of the power supply
     
     BRIGHTNESS = map(analogRead(A2),0,1023,0,200);
     //BRIGHTNESS = 80; // This value ranges from 0-255 but more than 100 is not recommended because the current will be too high.
     matrix_1.setBrightness(BRIGHTNESS);
     matrix_2.setBrightness(BRIGHTNESS);

     matrix_1.fillScreen(matrix_1.Color(red, green, blue));
     matrix_1.show();
     matrix_2.fillScreen(matrix_1.Color(red, green, blue));
     matrix_2.show();
     
  }

  void display_values()
  {
     //Bottom distance 
     Serial.print(" Db: ");
     Serial.print(average_2);
     //Top distance 
     Serial.print(" Dt: ");
     Serial.print(average);
     //IR angle
     Serial.print(" IR: ");
     Serial.print(angle_1);
     //RGB angle
     Serial.print(" RGB: ");
     Serial.print(angle_2);
     //Camera distance
     Serial.print(" Cd: ");
     Serial.print(distance_camera);
     //RGB brightness
     Serial.print("Bright: ");
     Serial.print(BRIGHTNESS);
     Serial.println();
  }

  void Set_Matrix_Color_Brightness(byte Red_int, byte Green_int, byte Blue_int, byte brightness)
  {
     //Update Matrix 1
     matrix_1.setBrightness(brightness);  
     matrix_1.fillScreen(matrix_1.Color(Red_int, Green_int, Blue_int));
     matrix_1.show();
  
     //Update Matrix 2
     matrix_2.setBrightness(brightness);
     matrix_2.fillScreen(matrix_2.Color(Red_int, Green_int, Blue_int));
     matrix_2.show();
  }
  
  void read_irradiance()
  {
    sensors_event_t event;
    tsl.getEvent(&event);
    float lux = event.light;
    if (red_selected == true)
    {
      float irradiance = 0.0028*lux - 0.0623;
      Serial.println(irradiance);
    }
    if (green_selected == true)
    {
      float irradiance = 0.0019*lux + 0.0155;
      Serial.println(irradiance);
    }
    if (blue_selected == true)
    {
      float irradiance = 0.0017*lux + 0.0059;
      Serial.println(irradiance);
    }
    
  }

  void intensity_ramp(byte max_value,unsigned int interval)
  {
    byte i = 0;
    while (i <= max_value)
    {
      if (timeElapsed > interval)
      {
        Set_Matrix_Color_Brightness(red, green, blue, i);
        Serial.println(i);
        timeElapsed = 0;
        i++;
      }
    }
  }
  
  void blinking(unsigned int interval_low, unsigned int interval)
  {
  unsigned long currentMillis = millis();    
  // RGB MATRICES SET COLOR NO COLOR
  Set_Matrix_Color_Brightness(red, green, blue, brightness_low);
  
  // Print intensity 0
  Serial.println(state);
//  Serial.print(" ");
//  Serial.println(millis());

  while (currentMillis > interval_low)
  {
    unsigned long currentMillis = millis();
    
    if (currentMillis - previousMillis >= interval) 
    {
      // save the last time you blinked the LED
      previousMillis = currentMillis;
  
      // if the state is off turn it on and vice-versa:
      if (state == LOW) 
        {
          state = HIGH;
          // RGB matrices set high color
          Set_Matrix_Color_Brightness(red, green, blue, brightness);
        } 
      else 
        {
          state = LOW;
          // RGB matrices set low color
          Set_Matrix_Color_Brightness(red, green, blue, brightness_low);
        }
        Serial.println(state);
//        Serial.print(" ");
//        Serial.println(millis());
      }  
      Serial.println(state);
//      Serial.print(" ");
//      Serial.println(millis());
    }
  }

  void read_spectral_sensor()
  {
    uint16_t readings[12];
    float counts[12];

    if (!as7341.readAllChannels(readings))
    {
      Serial.println("Error reading all channels!");
      return;
    }

    for(uint8_t i = 0; i < 12; i++) 
    {
      if(i == 4 || i == 5) continue;
      // we skip the first set of duplicate clear/NIR readings
      // (indices 4 and 5)
      counts[i] = as7341.toBasicCounts(readings[i]);
    }

  Serial.print("F1 415nm : ");
  Serial.println(counts[0]);
  Serial.print("F2 445nm : ");
  Serial.println(counts[1]);
  Serial.print("F3 480nm : ");
  Serial.println(counts[2]);
  Serial.print("F4 515nm : ");
  Serial.println(counts[3]);
  Serial.print("F5 555nm : ");
  // again, we skip the duplicates  
  Serial.println(counts[6]);
  Serial.print("F6 590nm : ");
  Serial.println(counts[7]);
  Serial.print("F7 630nm : ");
  Serial.println(counts[8]);
  Serial.print("F8 680nm : ");
  Serial.println(counts[9]);
  Serial.print("Clear    : ");
  Serial.println(counts[10]);
  Serial.print("NIR      : ");
  Serial.println(counts[11]);
  Serial.println();
  
  delay(500);
  }

  void Blink_from_Pi_serial()
  {
    if (Serial.available()>0)
    {
    // read the incoming string and convert to int
    int state2  = Serial.parseInt();
    
     if (state2  == 1) 
     {
          Set_Matrix_Color_Brightness(red, green, blue, brightness);
          //Serial.println(state2);
     }
     
     if (state2  == 0) 
     {
          Set_Matrix_Color_Brightness(red, green, blue, brightness_low); 
          //Serial.println(state2);
     }
    }
  }

  void Custom_intensity_from_Pi_serial()
  {
    value  = Serial.parseInt();
    int intensity = constrain(value, 0, 255);
    Set_Matrix_Color_Brightness(red, green, blue, intensity);
    //delay(1000);
    //Serial.println(intensity);
  }
  

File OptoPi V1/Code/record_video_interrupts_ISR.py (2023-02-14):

import tkinter as tk
import picamera
import time
import datetime as dt
import serial
import RPi.GPIO as GPIO
from time import sleep

interrupt_pin = 21
#GPIO.setwarnings(False)
GPIO.setmode(GPIO.BCM)
GPIO.setup(interrupt_pin, GPIO.OUT, initial=GPIO.LOW)


USB_PORT = "/dev/ttyACM0"
#USB_PORT = "/dev/ttyACM1"
parent_directory = '/home/pi/Documents/dmel'
date='2021_06_11'
exp='1DR_test'
lighting = 'red'
lighting_paradigm = 'OFF_ON'
gal4 = 'NA'
uas = 'NA'
experiment_name = parent_directory + '/' + date + '_' + gal4 + '_' + uas + '_' + lighting + '_' + lighting_paradigm + '_'+ exp


experiment_duration=60

def ON_ISR(stim_dur):
    #camera.annotate_text = str((dt.datetime.now()-start).total_seconds()) + '_ON'
    camera.annotate_text = 'ON'
    file.write('\n'+ str((dt.datetime.now()-start).total_seconds()) + '_ON')
    GPIO.output(interrupt_pin, GPIO.HIGH)
    sleep(stim_dur)
    

def OFF_ISR(stim_dur):
    camera.annotate_text = 'OFF'
    #camera.annotate_text = str((dt.datetime.now()-start).total_seconds()) + '_OFF'
    file.write('\n'+ str((dt.datetime.now()-start).total_seconds()) + '_OFF')
    GPIO.output(interrupt_pin, GPIO.LOW)
    sleep(stim_dur)

try:
   ser = serial.Serial(USB_PORT, 9600, timeout=1)
   ser.flush()
except:
   print("ERROR - Could not open USB serial port.  Please check your port name and permissions.")
   print("Exiting program.")
   exit()


with picamera.PiCamera() as camera:
        camera.resolution = (1000, 1200)
        camera.color_effects=(128,128)
        camera.framerate = 10
        camera.annotate_background = picamera.Color('black')
        camera.start_preview(alpha=250)
        file = open(experiment_name + "_log.csv","a")
        input('Press ENTER to start recording')
        start = dt.datetime.now()
        camera.start_recording(experiment_name + ".h264")
        while not (dt.datetime.now() - start).total_seconds() > experiment_duration:
            ON_ISR(0.1) #set whatever duration the light should be on in seconds
            OFF_ISR(0.1) #set whatever duration the light should be off in seconds

        camera.stop_recording()
        file.close()
        ser.flush()
ser.flush()

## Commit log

2021-12-06 RGB diffuser files
    [RGB diffuser.ipt, RGB diffuser.stl]
2022-01-09 Spectrometer data
    [Dotstar matrices spectrum.xlsx]
2022-02-18 Thorlabs spectrum data
    [Dotstar matrices spectrum.xlsx, Spectrometer data.xlsx]
2022-06-28 Belt tensioner update
    [Belt tensioner.stl]
2022-09-12 Belt tensioner V2
    [Belt tensioner.stl, Belt tensor V2.ipt]
2022-10-07 V1 folder
    [Acrylic base light source.SLDPRT, Acrylic base light source.ipt, Adult fly trap middle.0005.ipt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]
2022-11-30 PCBs update
    [Behavioural Device assembly 2.0020.iam, Behavioural Device assembly 2.iam, Light sources platform spacer 2.dwg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]
2022-12-01 Electronic board adaptors
    [Bill of materials (To be changed).xlsx, Camera_cart_V2.stl, Light sources platform spacer.stl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]
2022-12-08 ISR code
    [Bill of materials.xlsx]
2022-12-09 OptoPi V1
    [1-6 connector base.dwg, 1-6 connector base.dxf, 1-6 connector base.stp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]

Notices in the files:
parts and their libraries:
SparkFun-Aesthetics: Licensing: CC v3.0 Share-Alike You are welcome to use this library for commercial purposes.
